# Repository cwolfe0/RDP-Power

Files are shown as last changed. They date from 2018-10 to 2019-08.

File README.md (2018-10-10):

# RDP-Power
This is a PCB designed in KiCad for the UAH SHC HELEN project's Radiation Detection Payload (RDP).  This PCB is intended to receive power from 2-3 18650 battery "banks" with 2 batteries connecting to each of J1:6.  Then the voltage is stepped to appropriate levels for the power requirements of the RDP payload (+/-15V, +12V and +3.3V).  A BOM will be attached after a parts list is fully compiled.

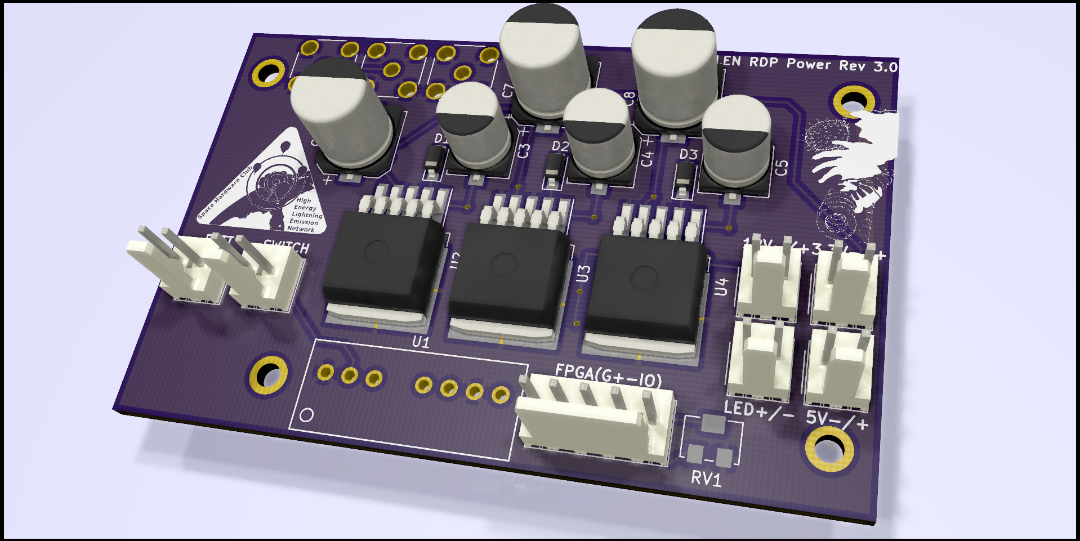
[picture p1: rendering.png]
PCB Rendering in KiCad


The rendering above is a rough idea of what this payload will look like with most of its components installed.  It is only missing the +/-15 V regulator in the bottom right and the mounting screws.

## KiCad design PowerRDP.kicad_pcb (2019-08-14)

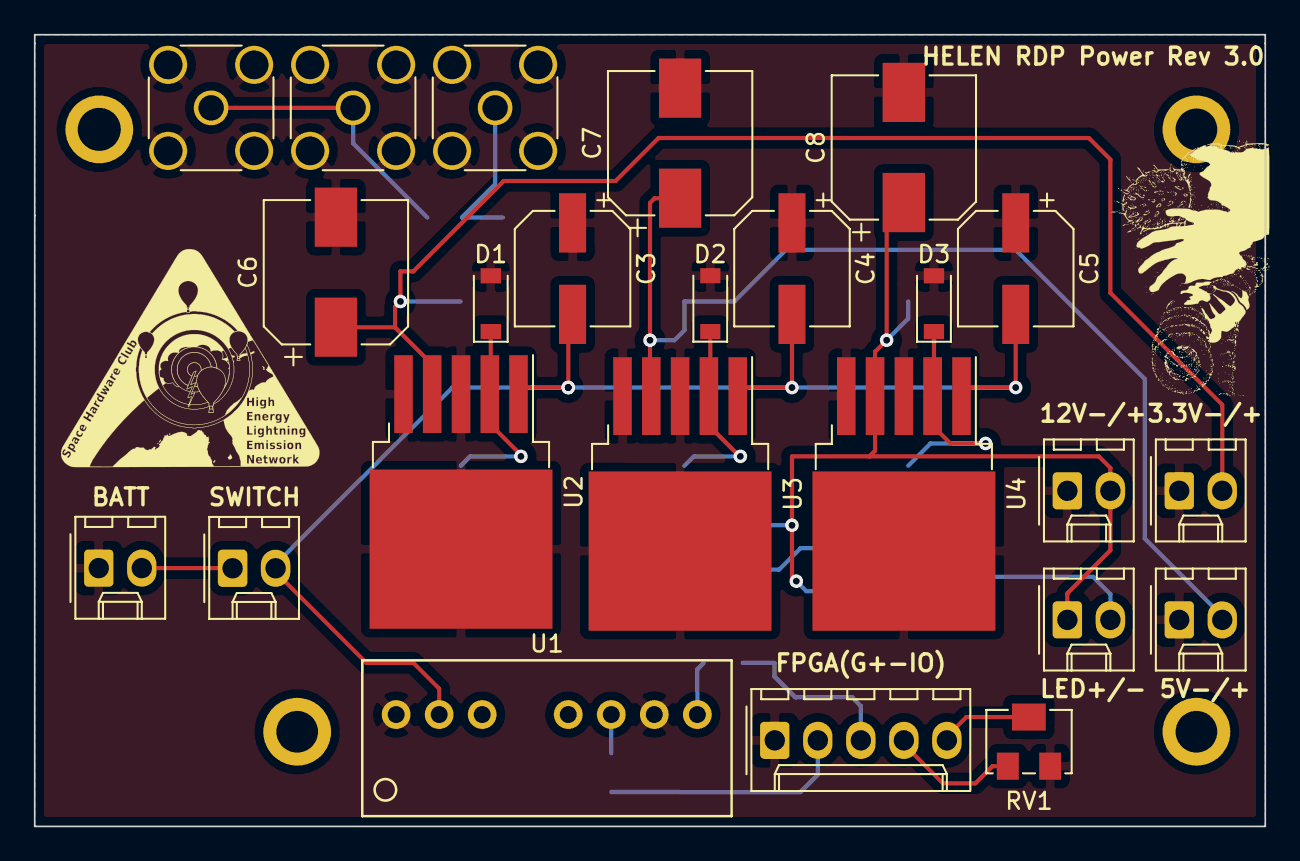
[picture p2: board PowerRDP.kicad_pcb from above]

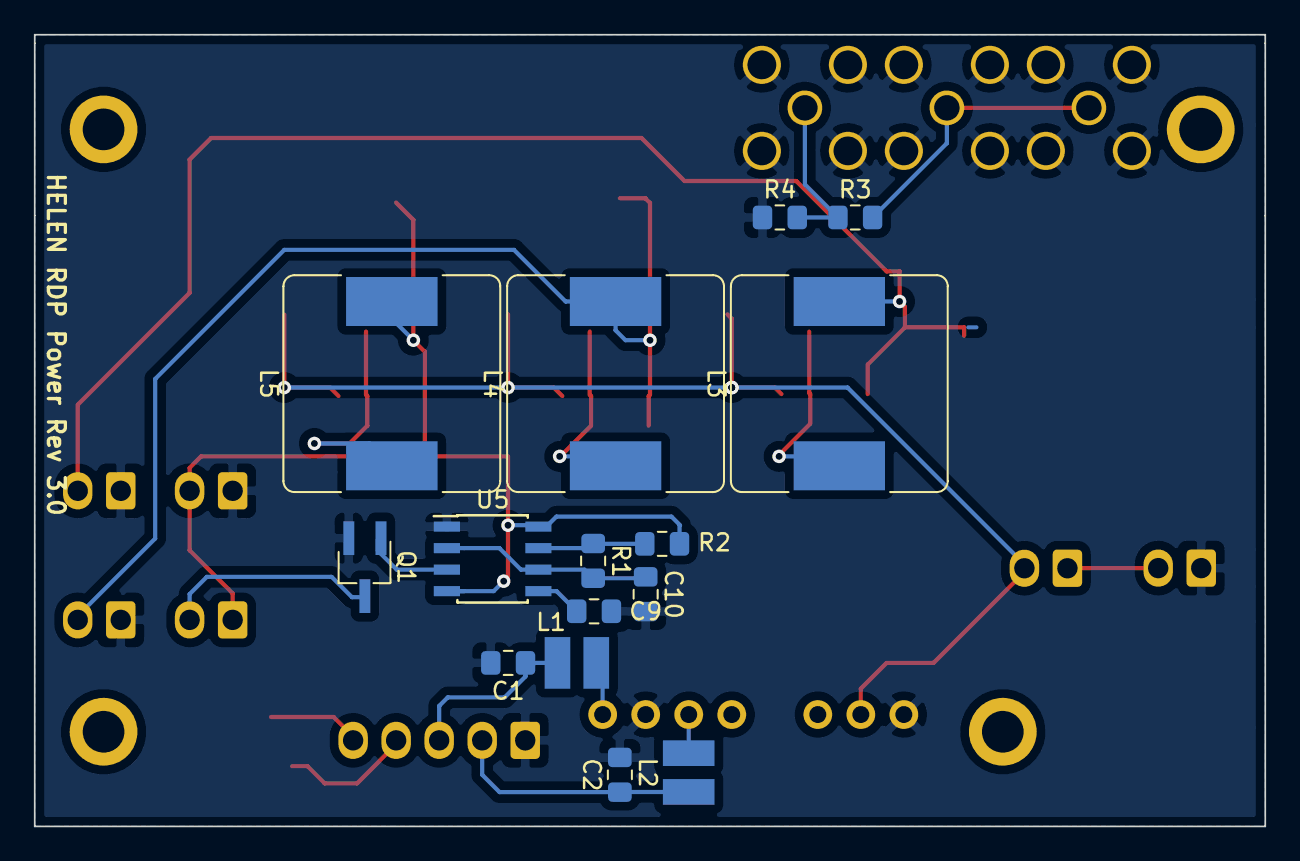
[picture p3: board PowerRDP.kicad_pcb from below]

Board: 2 copper layers, 72.6 x 46.7 mm, 39 parts (15 on the bottom side), 22 nets.

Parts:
C1, C2: 1 uF; C_0805_2012Metric_Pad1.15x1.40mm_HandSolder
C3, C4, C5: 100uF; CP_Elec_6.3x7.7
C6, C7, C8: 330uF; CP_Elec_8x10
C9: .01 uF; C_0805_2012Metric_Pad1.15x1.40mm_HandSolder
C10: 47 uF; C_0805_2012Metric_Pad1.15x1.40mm_HandSolder
D1, D2, D3: 1N5819; D_SOD-123
J1: Conn_01x02_Male; Molex_KK-254_AE-6410-02A_1x02_P2.54mm_Vertical
J2: Switch; Molex_KK-254_AE-6410-02A_1x02_P2.54mm_Vertical
J3, J4, J5: Conn_Coaxial; SMA_Amphenol_132134_Vertical
J6: 3.3V; Molex_KK-254_AE-6410-02A_1x02_P2.54mm_Vertical
J7: 5V; Molex_KK-254_AE-6410-02A_1x02_P2.54mm_Vertical
J8: 12V; Molex_KK-254_AE-6410-02A_1x02_P2.54mm_Vertical
J9: FAA LED; Molex_KK-254_AE-6410-02A_1x02_P2.54mm_Vertical
J10: SOCKET; Molex_KK-254_AE-6410-05A_1x05_P2.54mm_Vertical
L1, L2: 47 uH; Murata 8200
L3, L4, L5: 470uH; L_Bourns_SRR1260
Q1: NTR4003NT1G; TSOT-23_HandSoldering
R1, R2: 24k; R_0805_2012Metric_Pad1.15x1.40mm_HandSolder
R3: 1k; R_0805_2012Metric_Pad1.15x1.40mm_HandSolder
R4: 91; R_0805_2012Metric_Pad1.15x1.40mm_HandSolder
RV1: R_POT; Potentiometer_Bourns_3214W_Vertical
U1: Recom_RS3
U2: LM2575-3.3BU; TO-263-5_TabPin3
U3: LM2575-5.0BU; TO-263-5_TabPin3
U4: LM2575-12BU; TO-263-5_TabPin3
U5: TS555; SOIC-8_3.9x4.9mm_P1.27mm

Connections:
+BATT: J1.2, J2.1
/+3.3V: C6.1, J6.2, L3.2, U2.4
/+5V: C7.1, J7.2, L4.2, U3.4
/+12V: C8.1, J8.2, J9.1, L5.2, R2.1, U4.4, U5.4, U5.8
/+15V: C2.1, J10.2, L2.2
/-15V: C1.1, J10.3, L1.2
/ADC1: J3.1, J4.1, R3.2
/ADC2: J5.1, R3.1, R4.2
/C_in: J10.4, RV1.1
/C_out: J10.5, RV1.2
/FAA_GND: J9.2, Q1.3
/FAA_SIG: Q1.1, U5.3
/POWR: C3.2, C4.2, C5.2, J2.2, U1.2, U2.1, U3.1, U4.1
/THR: C10.1, R1.2, U5.2, U5.6
GND: C1.2, C2.2, C3.1, C4.1, C5.1, C6.2, C7.2, C8.2, C9.2, C10.2, D1.2, D2.2, D3.2, J1.1, J3.2, J4.2, J5.2, J6.1, J7.1, J8.1, J10.1, Q1.2, R4.1, RV1.3, U1.1, U1.7, U2.3, U2.5, U3.3, U3.5, U4.3, U4.5, U5.1
unnamed: C9.1, U5.5
unnamed: D1.1, L3.1, U2.2
unnamed: D2.1, L4.1, U3.2
unnamed: D3.1, L5.1, U4.2
unnamed: L1.1, U1.8
unnamed: L2.1, U1.6
unnamed: R1.1, R2.2, U5.7

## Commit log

2018-09-27 create PCB layout and GERBERs
    [PowerRDP-B.Cu.gbr, PowerRDP-B.Mask.gbr, PowerRDP-B.Paste.gbr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]
2018-09-27 add render of board from kicad
2018-09-27 add dimensions on PCB
    [PowerRDP.kicad_pcb]
2018-09-27 Add pole descriptions on bottom silkscreen of +/-15V output
    [PowerRDP.kicad_pcb]
2018-10-10 remove old +/-15V add new (kicad files broken)
    [PowerRDP.sch]
2018-10-16 Add power filtering to all regulators, correct +/-15V regulator
    [PowerRDP.kicad_pcb, PowerRDP.sch]
2018-10-18 update Gerbers
    [PowerRDP-B.Cu.gbl, PowerRDP-B.Cu.gbr, PowerRDP-B.Mask.gbr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]
2018-10-25 Re-add drill holes
    [PowerRDP-B.Cu.gbl, PowerRDP-B.Mask.gbs, PowerRDP-B.Paste.gbp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]
2018-10-25 Actually save the board this time to add mounting holes
    [PowerRDP.kicad_pcb]
2018-11-02 Slight fixes
    [PowerRDP-B.Cu.gbl, PowerRDP-B.Mask.gbs, PowerRDP-B.Paste.gbp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]
2019-01-10 Correct 15V regulator footprint, add potentiometer for socket gain control
    [PowerRDP.kicad_pcb, PowerRDP.sch]
2019-01-10 Increment revison
    [PowerRDP.kicad_pcb]
2019-02-02 Fix 15V regulator, add blinking FAA LEDs
    [PowerRDP-B.Cu.gbl, PowerRDP-B.Mask.gbs, PowerRDP-B.Paste.gbp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]
2019-02-02 Add silkscreen labels to connectors
    [PowerRDP-B.Cu.gbl, PowerRDP-B.Mask.gbs, PowerRDP-B.Paste.gbp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]
2019-02-04 Remake power board with updated single-output regulators. PCB entirely redesigned
    [PowerRDP-B.Cu.gbl, PowerRDP-B.Cu.gbr, PowerRDP-B.Mask.gbr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]
2019-02-04 Update diodes to something I can buy
    [PowerRDP-B.Cu.gbr, PowerRDP-B.Mask.gbr, PowerRDP-B.Paste.gbr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]
2019-02-04 Fix capcaitors and inductors and expand board to sustain girth of new components.
    [PowerRDP-B.Cu.gbr, PowerRDP-B.Mask.gbr, PowerRDP-B.Paste.gbr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]
2019-02-06 Add op amps and SMA connectors for socket voltage reduction
    [PowerRDP.sch]
2019-02-16 Change R3 to through-hole for easier changes of amplification
    [PowerRDP-B.Cu.gbr, PowerRDP-B.Mask.gbr, PowerRDP-B.Paste.gbr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]
2019-02-22 Fix opamps
    [PowerRDP-B.Cu.gbr, PowerRDP-B.Mask.gbr, PowerRDP-B.Paste.gbr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]
2019-02-22 Fix opamps by adding -V supply
    [PowerRDP-B.Cu.gbr, PowerRDP-B.Mask.gbr, PowerRDP-B.Paste.gbr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]
2019-02-22 Fix silkscreen overlaps
    [PowerRDP-B.Cu.gbr, PowerRDP-B.Mask.gbr, PowerRDP-B.Paste.gbr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]
2019-04-08 Update 555 timer resistor value to new 50% duty cycle
    [PowerRDP.sch]
2019-08-14 Update to rev3: fix 1/12 gain, simplify naming, general cleanup
    [PowerRDP.kicad_pcb]
